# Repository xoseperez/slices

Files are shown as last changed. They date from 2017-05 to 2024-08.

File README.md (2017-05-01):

# Slices

Slices is an ESP8266 based clock with a LED matrix display.

It's an evolution of a previous project ([a wordclock](http://tinkerman.cat/wordlock)), with the following goals:

* Replace the ATMega328P with an ESP8266 (NTP support and user interaction)
* Smaller sizes (8x8 LED matrices)
* Smaller PCB, less buttons (version 3.0 of the [DaClock](http://github.com/xoseperez/daclock) board)
* Add buzzer for alarms
* Replace the 3D printed part with a MDF grid cut in laser
* Completely closed enclosure, better presentation
* Fix some issues with the original board (like the lack of a beefy capacitor across the LED matrix power lines).

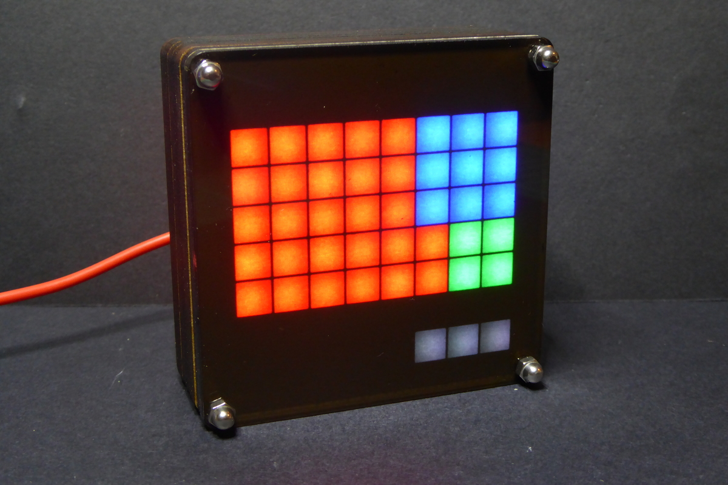
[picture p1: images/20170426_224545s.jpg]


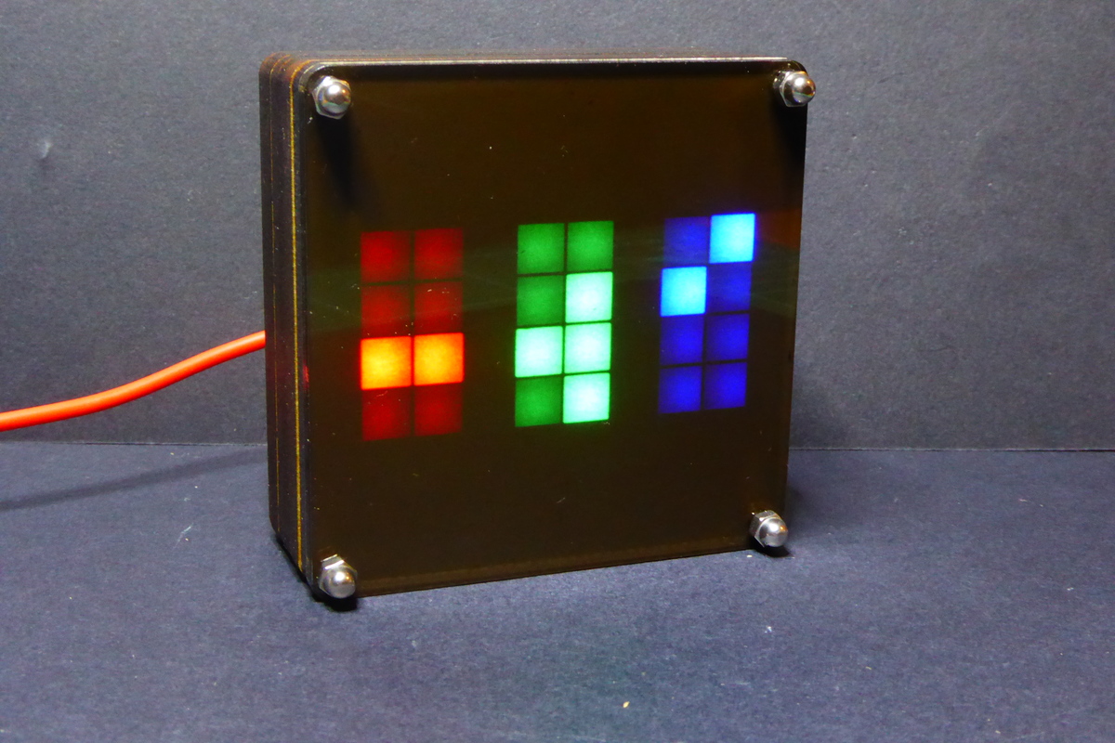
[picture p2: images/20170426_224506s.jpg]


## Hardware

### The clock

The hardware has been designed using [OpenSCad](http://www.openscad.org)
and it's inspired by the [PiBow](https://www.raspberrypi.org/blog/pibow/)
cases for Raspberry Pi. A series of layers forming a sandwich. From top to bottom
the layers are (this is true for beta version):

* front, a smoke colored acrylic layer cut with a laser cutter
* stencil (optional), a thin black cardboard with the characters cut out with a laser
* diffusor, a thin white paper sheet
* grid, a 3D printed black PLA grid to isolate each pixel or a thick laser cut MDF
* LED matrix, a 16x16 flexible RGB LED Matrix or a 8x8 PCB based one w/ WS2812B pixels
* LED matrix support in MDF
* MDF hollow layers to allow room for the electronics
* controller, custom PCB attached to the backend
* back, a clear acrylic layer or MDF again with holes for the power connector and button

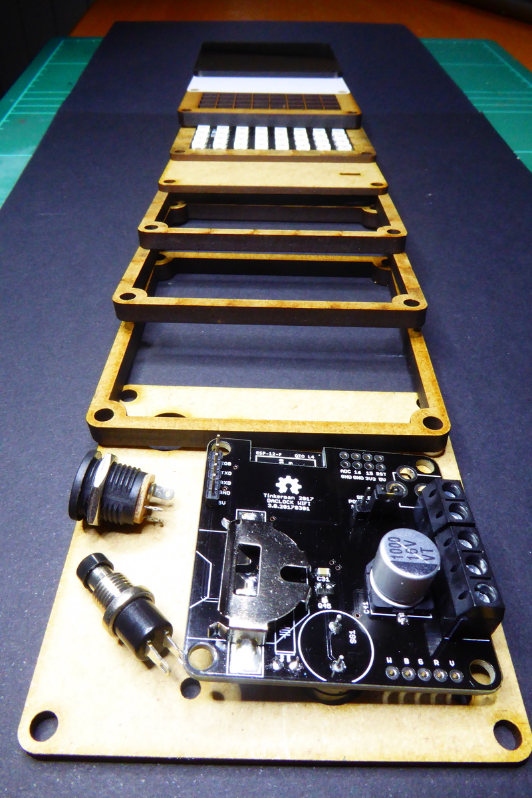
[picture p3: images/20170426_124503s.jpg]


### The controller

The controller is based on the the [DaClock](http://github.com/xoseperez/daclock)
board and it's designed to serve different purposes. This project uses version 3.0
of that board.

It features a ESP8266 ESP12E/F module, a DS1337 RTC clock, a buzzer for notifications
and connectors to drive a WS2812 LED matrix.

## Firmware

The project is ready to be build using [PlatformIO](http://www.platformio.org).
Please refer to their web page for instructions on how to install the builder.
Once installed:

```bash
> cd code
> platformio run
> platformio run --target upload
```

Library dependencies are automatically managed via PlatformIO Library Manager.

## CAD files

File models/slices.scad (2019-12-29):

//-----------------------------------
// CONFIGURATION
//-----------------------------------

// Matrix 16x16
grid_size=16;
grid_step=10;
grid_shift=0;

// Matrix 8x8
//grid_size=8;
//grid_step=8;
//grid_shift=0.4;

// Matrix 10x10
//grid_size=8;
//grid_step=10;
//grid_shift=0;

// LED circle 60
led_radius_inner=72.39;
led_radius_outer=78.74;
led_radius=(led_radius_inner+led_radius_outer)/2;
led_width=(led_radius_outer-led_radius_inner);
led_side=6;
led_count=60;
led_angle_shift=0;
led_circle_grid=1;

// LED circle 24
//led_radius_inner=72.22/2;
//led_radius_outer=85.5/2;
//led_radius=(led_radius_inner+led_radius_outer)/2;
//led_width=(led_radius_outer-led_radius_inner);
//led_side=6;
//led_count=24;
//led_angle_shift=0;
//led_circle_grid=0;

// General settings
grid_wall=1;
grid_height=5;
hole_size=4;
chamfer_size=4;
//font = "Ubuntu:style=Bold";
font = "AG Stencil:style=AG Stencil";

// Text for the 4 buttons in version 1
button_text = [
    "MODE",
    "LANGUAGE",
    "COLOR",
    "BRIGHTNESS"
];

// Stencil of characters for 16x16 matrix (catalan & spanish)
list_esp_cat_16 = [
    "ésónesonvoracasi",
    //"undostreslangmig",
    "unodostreslngmig", //<- add "uno"
    "quarts1imenysmig",
    "cinc2ben34tocats",
    "lesdelasduesiset",
    "cincochovuit&una",
    "dosnuevediezonce",
    "quatreseiscuatro",
    "sietedoce5ymenos",
    "&onzedotzenoudeu",
    "veinticincomedia",
    "cuartodiezveinte",
    "ben6tocadespunto",
    "tocadapasadas789",
    "dellamatinitarda",
    "mañanatardenoche"
];

// Stencil of characters for the 8x8 matrix (catalan)
list_cat_8 = [
    "1dos3les",
    "laquarts",
    "de0dotze",
    "&unacinc",
    "duesiset",
    "quatres0",
    "vuitnou0",
    "deu&onze"
];

//-----------------------------------

// Front face (translucid or dark acrylic, also for the difuser)
//layer_front(); 

// Character stencial (pass stencil array as argument)
layer_stencil(list_esp_cat_16);

// Grid (choose either a 3D model or a 2D model to laser cut)
//layer_grid_3D();
//layer_grid_2D();
//linear_extrude(4)
//layer_grid_circle();

// Layer to hold the PCB matrix layer in place (only for v2)
//layer_matrix();
//translate([0,0,2.5])
//linear_extrude(2.5)
//layer_matrix_circle();

// Matrix support layer, with cutouts for the cables, choose either version 1 or 2
//layer_support_v1();
//layer_support_v2();
//translate([0,0,2.5])
//linear_extrude(2.5)
//layer_support_circle();

// Hollow layer
//layer_hollow();

// Back layer
//layer_back_v1();
//layer_back_v2();

// demo
//linear_extrude(4)
//    sonometre();
//translate([0,0,-12])
//    linear_extrude(12)
//        layer_hollow();
//translate([0,0,-16])
//    linear_extrude(4)
//        layer_back_v2();

//-----------------------------------

module sonometre() {
    difference() {
        layer_grid_circle();
        translate([50,60])
            circle(5, $fn=50);    
        translate([50,40])
            circle(5, $fn=50);    
    }
}

module base(size, step, chamfer, hole) {
    size = (size+2)*step;
    difference() {
        translate([chamfer, chamfer, 0]) {
            minkowski() {
                square(size-2*chamfer);
                circle(chamfer, $fn=50);
            }
        }
        hole = hole / 2;
        hole_center = (step) / 2;
        translate([hole_center,hole_center,0]) {
            circle(hole, center=true, $fn=50);
        }
        translate([size-hole_center,hole_center,0]) {
            circle(hole, center=true, $fn=50);
        }
        translate([size-hole_center,size-hole_center,0]) {
            circle(hole, center=true, $fn=50);
        }
        translate([hole_center,size-hole_center,0]) {
            circle(hole, center=true, $fn=50);
        }
    }
}

module grid(size, step, wall) {
    for (x=[1:size]) {
        for (y=[1:size]) {
            translate([x*step+wall/2,y*step+wall/2,0]) {
                square(step-wall);
            }
        }
    }
}

module subgrid(size, step, wall) {
    for (x=[1:size]) {
        translate([x*step+wall/2,wall/2,wall]) {
            cube([step-wall,step-wall,step]);
        }
        translate([x*step+wall/2,(size+1)*step+wall/2,wall]) {
            cube([step-wall,step-wall,step]);
        }
    }
    for (y=[1:size]) {
        translate([wall/2,y*step+wall/2,wall]) {
            cube([step-wall,step-wall,step]);
        }
        translate([(size+1)*step+wall/2,y*step+wall/2,wall]) {
            cube([step-wall,step-wall,step]);
        }
    }
}

module layer_grid_circle() {

    difference() {
        base(grid_size, grid_step, chamfer_size, hole_size);
        offset = (grid_size+2)*grid_step/2;
        translate([offset,offset]) {
            for (i=[0:led_count]) {
                rotate(360 * (i+led_angle_shift)/led_count)
                    translate([0, led_radius])
                        square([led_side, led_side], true);
            }
        }
        if (led_circle_grid)        
            translate([50,50])
                grid(8, 8, 1);
    }
}
    
module layer_matrix_circle() {

    difference() {
        base(grid_size, grid_step, chamfer_size, hole_size);
        offset = (grid_size+2)*grid_step/2;
        translate([offset,offset]) {
            difference() {
                circle(led_radius_outer, $fn=100);
                circle(led_radius_inner, $fn=100);
            }
        }
        if (led_circle_grid)
            translate([58,58])
                square([64,64]);
    }
}

module layer_grid_2D()  {
        difference() {
            base(grid_size, grid_step, chamfer_size, hole_size);
            translate([0, grid_shift])
                grid(grid_size, grid_step, grid_wall);
        }
}

module layer_grid_3D() {
    difference() {
        linear_extrude(grid_height) layer_grid_2D();
        subgrid(grid_size, grid_step, grid_wall);
    }
}

module arc(max, min) {
    union() {
        intersection() {
            difference() {
                circle(max, $fn=50);
                circle(min, $fn=50);
            }
            square(max,center=false);
        }
        translate([0,min]) square([5, 15-min], center=false);
    }
}

module layer_front() {
    base(grid_size, grid_step, chamfer_size, hole_size);
}

module layer_support_v1() {
    difference() {
        base(grid_size, grid_step, chamfer_size, hole_size);
        translate([5,5,0]) arc(10,5);
        translate([(grid_size+2)*grid_step-5,5,0]) {
            mirror([1,0,0]) arc(10,5);
        }
    }
}

module layer_support_v2() {
    difference() {
        base(grid_size, grid_step, chamfer_size, hole_size);
        translate([grid_step*1.5,grid_step*8 + 1,0]) {
            square([1.5*(grid_step-grid_wall),grid_wall*4], true);
        }
        translate([grid_step*8.5,grid_step*2 - 1,0]) {
            square([1.5*(grid_step-grid_wall),grid_wall*4], true);
        }
    }
}

module layer_support_circle() {
    difference() {
        base(grid_size, grid_step, chamfer_size, hole_size);
        offset = (grid_size+2)*grid_step/2;
        shift = 360*(0.5-led_angle_shift)/led_count;
        translate([offset,offset]) {
            for (i=[0:3]) {
                rotate(90*i-shift)
                    translate([0, led_radius])
                        square([led_width*2,led_width], true);
            }
        }
        if (led_circle_grid)
            translate([64, 64]) {
                translate([8*0,8*6]) {
                    square([1.75*(8-1),1*4], false);
                }
                translate([8*5,8*0,0]) {
                    square([1.75*(8-1),1*4], false);
                }
            }
    }
}

module layer_hollow() {
    border = grid_step/2;
    size = (grid_size+2)*grid_step - border*2;
    difference() {
        base(grid_size, grid_step, chamfer_size, hole_size);
        translate([border,border]) 
            difference() {
                square(size);
                circle(5, $fn=50);
                translate([size,0]) circle(5, $fn=50);
                translate([size,size]) circle(5, $fn=50);
                translate([0,size]) circle(5, $fn=50);
            }
    }
}

module wall_hole() {
    minkowski() {
        square([0.1,15], center=true);
        circle(3, $fn=50);
    }
}

module socket_hole() {
    circle(11.4/2, $fn=50);
}

module buttons() {
    for (x=[0:3]) {
        translate([0,x*12]) {
            circle(3.6, $fn=50);
            translate([6,-2.5]) 
                text(button_text[x], 6, font,"right","center");
        }
    }
}

module layer_back_v1() {
    difference() {
        base(grid_size, grid_step, chamfer_size, hole_size);
        translate([50,30,0]) wall_hole();
        translate([(grid_size+2)*grid_step-50,30,0]) wall_hole();
        translate([(180-51)/2-4,110+(180-80)/2+4,0])
            rotate(-90)
                pcbfootprint();
    }
}
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

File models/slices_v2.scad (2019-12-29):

//-----------------------------------
// Layers to render
//-----------------------------------

//layer_front(); 
//layer_grid();
//layer_cast();
//layer_support();
//layer_hollow();
//layer_hollow_broken_middle();
//layer_hollow_broken_side();
//layer_back_wall();
//layer_back_v2();
//layer_back_v3(0);

//-----------------------------------
// Components to display
//-----------------------------------

show_big_square_grid=0;
show_small_square_grid=0;
show_two_small_square_grid=0;
show_big_circle_grid=0;
show_small_circle_grid=1;
show_potentiometer=1;
show_microphone=1;
show_fibonacci=0;

//-----------------------------------
// Configuration
//-----------------------------------

// Model size
//model_size=180;
model_size=100;
//model_size=80;

// Grid types (size, step, shift, wall)
grid = [
    [16, 10, 0, 1],
    [8, 8, 0.4, 1]
];

// Circle types (count, inner, outer)
circle = [
    [60, 71.5, 79.5],
    [24, 35.5, 43.5]
];

// Height of the grid (widt of the wood)
wood_width=4;

// Size of an individual LED
led_side=6;

// Shift LED circle 
led_shift = 0;

// Holes radius (half of metric: M3, M4...)
hole_size=2; // M4

// Hole distance to edge
hole_distance=5;

// Minkowski radius
chamfer_size=4;

// Fonts
//font = "Ubuntu:style=Bold";
font = "AG Stencil:style=AG Stencil";

//-----------------------------------
// DO NOT TOUCH BELOW THIS LINE
//-----------------------------------

//-----------------------------------
// Components
//-----------------------------------

module base() {
    
    difference() {
        
        // Shape
        minkowski() {
            square(model_size-2*chamfer_size, true);
            circle(chamfer_size, $fn=50);
        }

        // Holes
        for(i=[0:3]) {
            rotate(90*i) {
                translate([model_size/2-hole_distance,model_size/2-hole_distance,0]) {
                    circle(hole_size, center=true, $fn=50);
                }
            }
        }

    }
}

module fibonacci_block(type, number, x, y) {
    
    size = grid[type][0];
    step = grid[type][1] * (type == 0 ? 2 : 1);
    shift = grid[type][2];
    wall = grid[type][3];

    width = step * number - wall;
    x = x * step + wall/2;
    y = y * step + wall/2;
    translate([x,y]) square(width);

}

module fibonacci_negative(type) {

    size = grid[type][0];
    step = grid[type][1];
    shift = grid[type][2];
    wall = grid[type][3];
    
    translate([shift-size*step/2,-size*step/2]) {
        
        union() {
            fibonacci_block(type, 5, 0, 2);
            fibonacci_block(type, 3, 5, 4);
            fibonacci_block(type, 2, 6, 2);
            fibonacci_block(type, 1, 5, 3);
            fibonacci_block(type, 1, 5, 2);
        }

    }
    
}

module led_matrix_negative(type) {

    size = grid[type][0];
    step = grid[type][1];
    shift = grid[type][2];
    wall = grid[type][3];
    
    translate([shift-size*step/2,-size*step/2])
    for (x=[0:size-1]) {
        for (y=[0:size-1]) {
            translate([x*step+wall/2,y*step+wall/2,0]) {
                square(step-wall);
            }
        }
    }

}

module led_circle_negative(type, led_side, shift) {

    count = circle[type][0];
    inner = circle[type][1];
    outer = circle[type][2];
    radius = (inner + outer)/2;

    for (i=[0:count]) {
        rotate(360 * (i+shift) / count)
            translate([0, radius])
                square([led_side, led_side], true);
    }

}
    
module arc(max, min) {
    union() {
        intersection() {
            difference() {
                circle(max, $fn=50);
                circle(min, $fn=50);
            }
            square(max,center=false);
        }
        translate([0,min]) square([5, 15-min], center=false);
    }
}

module joint() {
    size = hole_size/0.75;
    translate([-size/2-0.25,0])
        union() {
            circle(size/2, $fn=50);
            translate([0,-size/4])
                square([size, size/2]);
        }
}

module potentiometer_negative(mark=0, body=0) {
    if (body==0) circle(4, $fn=50);
    if (mark) {
        translate([7.5,0,0])
            square([1,2.5], true);
        translate([-7.5,0,0])
            square([1,2.5], true);
    }
    if (body==1) circle(16, $fn=50);
}

module mic_negative(body=0) {
    union() {
        circle(5, $fn=50);
        if (body==1) square([12,3], true);
    }
}

module wall_hole() {
    rotate(180)
        minkowski() {
            square([0.1,15]);
            circle(3, $fn=50);
        }
}

module socket_hole() {
    circle(11.4/2, $fn=50);
}

module pcbfootprint_daclock_v2(hole=4) {

    // HOLES
    hole = hole / 2;
    translate([4,4,0]) {
        circle(hole, center=true, $fn=50);
    }
    translate([84,4,0]) {
        circle(hole, center=true, $fn=50);
    }
    translate([4,55,0]) {
        circle(hole, center=true, $fn=50);
    }
    translate([84,55,0]) {
        circle(hole, center=true, $fn=50);
    }
    
    // BUTTONS
    //translate([23,44,0]) {
        //square([54,13]);
    //}
    
    // SPEAKER
    translate([49, 36]) circle(6.5, $fn=50);

}


module pcbfootprint_daclock_v3() {
    
    hole_vector = sqrt(22*22*2);
    
    // PCB holes
    for(i = [45:90:315]) {
        rotate([0,0,i]) {
            translate([0,hole_vector]) {
                circle(1.5, $fn=50);
            }
        }
    }
    
    // speaker
    translate([1,3.5-22]) {
        circle(6.5, $fn=50);
    }
    

}

//-----------------------------------
// Layers
//-----------------------------------

module layer_front() {
    difference() {
        base();
        if (show_potentiometer) translate([0, -15]) potentiometer_negative(0);
        if (show_microphone) translate([0, 15]) mic_negative(0);
    }
}

module layer_grid() {

    difference() {
        
        base();
        
        if (show_big_square_grid) {
            led_matrix_negative(0);
            if (show_fibonacci) fibonacci_negative(0);
        }
        if (show_small_square_grid) {
            led_matrix_negative(1);
            if (show_fibonacci) fibonacci_negative(1);
        }
        if (show_two_small_square_grid) {
            translate([grid[1][0]*grid[1][1]/2-grid[1][2],0]) 
                led_matrix_negative(1);
            translate([-grid[1][0]*grid[1][1]/2-grid[1][2],0]) 
                led_matrix_negative(1);
        }
        if (show_big_circle_grid) 
            led_circle_negative(0, led_side, led_shift);
        if (show_small_circle_grid) 
            led_circle_negative(1, led_side, led_shift);
        
        if (show_potentiometer) translate([0,-15]) potentiometer_negative(1,0);
        if (show_microphone) translate([0,15]) mic_negative(0);
        
    }


}

module layer_cast() {

    difference() {
        
        base();
        
        if (show_big_square_grid) 
            square(grid[0][0]*grid[0][1]+2, true);
        if (show_small_square_grid)
            square(grid[1][0]*grid[1][1]+2, true);
        if (show_two_small_square_grid)
            square([grid[1][0]*grid[1][1]*2+2,grid[1][0]*grid[1][1]+2], true);
        if (show_big_circle_grid) {
            difference() {
                circle(circle[0][2], center=true, $fn=100);
                circle(circle[0][1], center=true, $fn=100);
            }
        }
        if (show_small_circle_grid) {
            difference() {
                circle(circle[1][2], center=true, $fn=100);
                circle(circle[1][1], center=true, $fn=100);
            }
        }
        if (show_potentiometer) translate([0,-15]) potentiometer_negative(1,0);
        if (show_microphone) translate([0,15]) mic_negative(1);
        
    }

}

module layer_support() {

    difference() {
        
        base();
        
        if (show_big_square_grid) {

            translate([
                model_size/2-hole_distance,
                model_size/2-hole_distance
            ]) rotate(180) arc(10,5);
            translate([
                -model_size/2+hole_distance,
                model_size/2-hole_distance
            ]) rotate(180) mirror([1,0,0]) arc(10,5);
        }
        
        if (show_small_square_grid || show_two_small_square_grid) {

            size = grid[1][0];
            step = grid[1][1];
            shift = grid[1][2];
            wall = grid[1][3];
            
            height = size;
            width = show_two_small_square_grid ? height * 2 : height;

            translate([0, step*(height/2-1)])
                square([step*width,step*2], true);
            translate([0, -step*(height/2-1)])
                square([step*width,step*2], true);


            
        }
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

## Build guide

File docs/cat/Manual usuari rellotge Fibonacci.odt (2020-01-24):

1:24 | 3:30
5:49 | 7:17
9:26 | 9:26 (també)
Mitjanit (0:00) | Migdia (12:00)

Rellotge de Fibonacci

La sèrie de Fibonacci és aquella on cada número és la suma dels dos anteriors de la sèrie: 1, 1, 2, 3, 5, 8, 13, ... El Rellotge de Fibonacci està compost per diferents àrees que tenen de costat els primers 5 números de la sèrie, que sumen 12 (1+1+2+3+5).

Com es calcula l’hora?

- Sumant els valors de les àrees en vermell i blau tens les hores.
- Sumant els valors de les àrees en verd i blau, multiplicant per 5 i sumant els els quadradets en taronja (M) tens els minuts.

Una mateixa hora es pot representar amb combinacions diferents. Les 5, per exemple, poden ser 1+1+3 o 2+3 o només 5. El mateix passa amb els minuts, de manera que el rellotge acostuma a mostrar l’hora d’una manera molt acolorida i diferent cada vegada.

A més, prement el botó del darrera, pots canviar entre mode rellotge o mode làmpada de colors.

El Rellotge de Fibonacci està pensat perquè es posi en hora automàticament a través d’Internet. Per fer-ho caldrà que el tinguis connectat al teu router de casa. Si prefereixes no fer-ho també hi ha la opció de posar-lo en hora manualment. Si aquest és el cas salta a l’apartat «Configuració manual».

Connectar-lo a la WiFi via WPS

La manera més ràpida de connectar el rellotge a la WiFi de casa és via el protocol WPS que incorporen la majoria de routers domèstics. Normalment hi ha un botó físic en el router etiquetat «WPS» que cal prémer durant uns segons (o fer doble-clic) per activar aquesta opció. Consulta el manual del teu router per saber si té WPS i com activar-lo.

Per configurar la connexió fent servir WPS cal seguir aquestes passes (millor si estàs a prop del router):

1. Desendolla el rellotge
2. Activa el mode WPS del teu router
3. Prem i no deixis anar el botó de la part del darrera del rellotge
4. Endolla el rellotge
5. Quan l’indicador d’estat estigui porpra ja pots deixar anar el botó

Si la negociació amb el router té èxit l’indicador d’estat canviarà a taronja (connectant) i després a verd (connectat). En aquest moment el rellotge consultarà l’hora i aquesta s’actualitzarà. Si l’indicador d’estat passa a vermell o està en porpra més d’un minut prova repetir el procediment. En cas de que continuï sense funcionar passa al procés de configuració manual (següent apartat).

Configuració manual

Amb el rellotge endollat i l’indicador d’estat apagat, fes doble clic al botó. L’indicador d’estat passarà a blau indicant que el rellotge ha creat un xarxa WiFi que pots fer servir per connectar-te i configurar-lo.

Pots buscar aquesta xarxa WiFi amb el teu mòbil o ordinador. El seu nom serà «SLICES_XXXXXX» on les X són números i lletres. Per defecte és una xarxa oberta, sense mot de pas. Un cop connectat obre un navegador web i vés a l’adreça «http://192.168.4.1».

Se’t presentarà un lloc web de configuració amb diferents opcions. A continuació tens una petita explicació de les més importants.

Des de la pestanya STATUS pots sincronitzar l’hora del rellotge amb la del teu ordinador o mòbil prement el botó «Sync».

Des de la pestanya WIFI pots configurar manualment la connexió al router de casa teva prement «Add Network». Es poden configurar diferents connexions.

Des de la pestanya TIME pots definir com vols sincronitzar el rellotge. Les opcions són:

- Connectar-se cada X hores: si el rellotge disposa de les credencials de connexió al nostre router, aquest es connectarà a la WiFi cada X hores i sincronitzarà l’hora per Internet. Pots indicar un valor d’hores d’entre 1 (cada hora, no recomanable) i 168 (un cop a la setmana).
- Connectar-se cada dia a una hora concreta: si el rellotge disposa de les credencials de connexió al nostre router, aquest es connectarà a la WiFi a l’hora indicada i sincronitzarà l’hora per Internet. Això és útil si només tens la WiFi accessible a determinades hores del dia.
- No connectar-se, només manualment: en aquest cas el rellotge no es connectarà automàticament i hauràs de fer doble clic al botó del rellotge perquè aquest es connecti a Internet per consultar l’hora o, si no té les dades de la WiFi, generar un punt d’accés propi per connectar-se i sincronitzar l’hora manualment tal com s’ha explicat en aquest mateix apartat.

Alimentació

El rellotge s’ha d’alimentar a 5V i un mínim de 0.5A. El connector és de tipus 5.5x2.1mm, centre positiu.

Indicador d’estat

Un dels «píxels» del rellotge és l’indicador d’estat («E» a la figura de la primera plana). El color d’aquest indica l’estat en el que es troba la connexió.

Aquest és un producte de codi i maquinari lliures dissenyat i fabricat per Xose Pérez (xose@tinkerman.cat). En els següents enllaços pots trobar les fonts de codi, disseny de la caixa i de l’electrònica així com documentació sobre l’ús del rellotge.

https://github.com/xoseperez/slices
https://github.com/xoseperez/daclock

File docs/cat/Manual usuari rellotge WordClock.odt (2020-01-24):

WordClock

Un wordclock o rellotge de paraules és un tipus de rellotge que «diu» l’hora en comptes de «marcar» l’hora. Per saber quina hora és simplement s’ha de llegir: «són vora tres quarts de sis de la tarda».

e | s | ó | n | e | s | o | n | v | o | r | a | c | a | s | i
u | n | o | d | o | s | t | r | e | s | l | n | g | m | i | g
q | u | a | r | t | s | 1 | i | m | e | n | y | s | m | i | g
c | i | n | c | 2 | b | e | n | 3 | 4 | t | o | c | a | t | s
l | e | s | d | e | l | a | s | d | u | e | s | i | s | e | t
c | i | n | c | o | c | h | o | v | u | i | t | d’ | u | n | a
d | o | s | n | u | e | v | e | d | i | e | z | o | n | c | e
q | u | a | t | r | e | s | e | i | s | c | u | a | t | r | o
s | i | e | t | e | d | o | c | e | 5 | y | m | e | n | o | s
d’ | o | n | z | e | d | o | t | z | e | n | o | u | d | e | u
v | e | i | n | t | i | c | i | n | c | o | m | e | d | i | a
c | u | a | t | r | o | d | i | e | z | v | e | i | n | t | e
b | e | n | 6 | t | o | c | a | d | e | s | p | u | n | t | o
t | o | c | a | d | a | p | a | s | a | d | a | s | 7 | 8 | 9
d | e | l | l | a | m | a | T | í | n | i | t | a | r | d | a
m | a | ñ | a | n | a | t | a | r | d | e | n | o | c | h | e

Evidentment l’hora dita dependrà de l’idioma. Aquest rellotge diu la hora en català o castellà, en funció del mode en el que es trobi. Per canviar de mode només cal prémer un cop el botó del darrera del rellotge. Els modes disponibles són:

Hora en català Hora en castellà | Hora en català amb «efecte matrix» Hora en castellà amb «efecte matrix»

El WordClock està pensat perquè es posi en hora automàticament a través d’Internet. Per fer-ho caldrà que el tinguis connectat al teu router de casa. Si prefereixes no fer-ho també hi ha la opció de posar-lo en hora manualment. Si aquest és el cas salta a l’apartat «Configuració manual».

Connectar-lo a la WiFi via WPS

La manera més ràpida de connectar el rellotge a la WiFi de casa és via el protocol WPS que incorporen la majoria de routers domèstics. Normalment hi ha un botó físic en el router etiquetat «WPS» que cal prémer durant uns segons (o fer doble-clic) per activar aquesta opció. Consulta el manual del teu router per saber si té WPS i com activar-lo.

Per configurar la connexió fent servir WPS cal seguir aquestes passes (millor si estàs a prop del router):

1. Desendolla el rellotge
2. Activa el mode WPS del teu router
3. Prem i no deixis anar el botó de la part del darrera del rellotge
4. Endolla el rellotge
5. Quan vegis un «1» blau fosc a la pantalla ja pots deixar anar el botó

Si la negociació amb el router té èxit s’il·luminarà un «3» (connectant) i després un «4» (connectat). En aquest moment el rellotge consultarà l’hora i aquesta s’actualitzarà. Si en comptes d’això el rellotge mostra un «5» blau o aquest «1» està estàtic més d’un minut prova repetir el procediment. En cas de que continuï sense funcionar passa al procés de configuració manual (següent apartat).

Configuració manual

Amb el rellotge endollat i cap número a la pantalla, fes doble clic al botó. Es mostrarà breument un «2» blau a la pantalla indicant que el rellotge ha creat un xarxa WiFi que pots fer servir per connectar-te i configurar-lo.

Pots buscar aquesta xarxa WiFi amb el teu mòbil o ordinador. El seu nom serà «SLICES_XXXXXX» on les X són números i lletres. Per defecte és una xarxa oberta, sense mot de pas. Un cop connectat obre un navegador web i vés a l’adreça «http://192.168.4.1».

Se’t presentarà un lloc web de configuració amb diferents opcions. A continuació tens una petita explicació de les més importants.

Des de la pestanya STATUS pots sincronitzar l’hora del rellotge amb la del teu ordinador o mòbil prement el botó «Sync».

Des de la pestanya WIFI pots configurar manualment la connexió al router de casa teva prement «Add Network». Es poden configurar diferents connexions.

Des de la pestanya TIME pots definir com vols sincronitzar el rellotge. Les opcions són:

- Connectar-se cada X hores: si el rellotge disposa de les credencials de connexió al nostre router, aquest es connectarà a la WiFi cada X hores i sincronitzarà l’hora per Internet. Pots indicar un valor d’hores d’entre 1 (cada hora, no recomanable) i 168 (un cop a la setmana).
- Connectar-se cada dia a una hora concreta: si el rellotge disposa de les credencials de connexió al nostre router, aquest es connectarà a la WiFi a l’hora indicada i sincronitzarà l’hora per Internet. Això és útil si només tens la WiFi accessible a determinades hores del dia.
- No connectar-se, només manualment: en aquest cas el rellotge no es connectarà automàticament i hauràs de fer doble clic al botó del rellotge perquè aquest es connecti a Internet per consultar l’hora o, si no té les dades de la WiFi, generar un punt d’accés propi per connectar-se i sincronitzar l’hora manualment tal com s’ha explicat en aquest mateix apartat.

Alimentació

El rellotge s’ha d’alimentar a 5V i un mínim de 1A. El connector és de tipus 5.5x2.1mm, centre positiu.

Indicador d’estat

En determinats moments el rellotge mostra un número de color blau fosc en pantalla. Aquest número és informatiu de l’estat en el que es troba la connexió WiFi. Els possibles valors són:

WPS Connectant-se al router Connectat al router | Punt d’accés Error

Aquest és un producte de codi i maquinari lliures dissenyat i fabricat per Xose Pérez (xose@tinkerman.cat). En els següents enllaços pots trobar les fonts de codi, disseny de la caixa i de l’electrònica així com documentació sobre l’ús del rellotge.

https://github.com/xoseperez/slices
https://github.com/xoseperez/daclock

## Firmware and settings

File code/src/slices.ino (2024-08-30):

/*

slices

Copyright (C) 2017-2024 by Xose Pérez <xose dot perez at gmail dot com>

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
*/

#include "config/all.h"
#include <Wire.h>

// -----------------------------------------------------------------------------
// METHODS
// -----------------------------------------------------------------------------

void heartbeat() {

    static unsigned long last_uptime = 0;
    static unsigned char uptime_overflows = 0;

    if (millis() < last_uptime) ++uptime_overflows;
    last_uptime = millis();
    unsigned long uptime_seconds = uptime_overflows * (UPTIME_OVERFLOW / 1000) + (last_uptime / 1000);
    unsigned int free_heap = ESP.getFreeHeap();

    DEBUG_MSG_P(PSTR("[MAIN] Uptime: %ld seconds\n"), uptime_seconds);
    DEBUG_MSG_P(PSTR("[MAIN] Free heap: %d bytes\n"), free_heap);
    #if ENABLE_ADC_VCC
        DEBUG_MSG_P(PSTR("[MAIN] Power: %d mV\n"), ESP.getVcc());
    #endif

    #if ENABLE_MQTT

        #if (MQTT_REPORT_INTERVAL)
            mqttSend(MQTT_TOPIC_INTERVAL, HEARTBEAT_INTERVAL / 1000);
        #endif
        #if (MQTT_REPORT_APP)
            mqttSend(MQTT_TOPIC_APP, APP_NAME);
        #endif
        #if (MQTT_REPORT_VERSION)
            mqttSend(MQTT_TOPIC_VERSION, APP_VERSION);
        #endif
        #if (MQTT_REPORT_HOSTNAME)
            mqttSend(MQTT_TOPIC_HOSTNAME, getSetting("hostname").c_str());
        #endif
        #if (MQTT_REPORT_IP)
            mqttSend(MQTT_TOPIC_IP, getIP().c_str());
        #endif
        #if (MQTT_REPORT_MAC)
            mqttSend(MQTT_TOPIC_MAC, WiFi.macAddress().c_str());
        #endif
        #if (MQTT_REPORT_RSSI)
            mqttSend(MQTT_TOPIC_RSSI, String(WiFi.RSSI()).c_str());
        #endif
        #if (MQTT_REPORT_UPTIME)
            mqttSend(MQTT_TOPIC_UPTIME, String(uptime_seconds).c_str());
        #endif
        #if (MQTT_REPORT_FREEHEAP)
            mqttSend(MQTT_TOPIC_FREEHEAP, String(free_heap).c_str());
        #endif
        #if (MQTT_REPORT_STATUS)
            mqttSend(MQTT_TOPIC_STATUS, MQTT_STATUS_ONLINE);
        #endif

    #endif

}

void hardwareSetup() {
    Serial.begin(SERIAL_BAUDRATE);
    Wire.begin(SDA_PIN, SCL_PIN);
}

void hardwareLoop() {

    // Heartbeat
    static unsigned long last_uptime = 0;
    if ((millis() - last_uptime > HEARTBEAT_INTERVAL) || (last_uptime == 0)) {
        last_uptime = millis();
        heartbeat();
    }

}

// -----------------------------------------------------------------------------
// BOOTING
// -----------------------------------------------------------------------------

void welcome() {

    DEBUG_MSG_P(PSTR("%s %s\n"), (char *) APP_NAME, (char *) APP_VERSION);
    DEBUG_MSG_P(PSTR("%s\n%s\n\n"), (char *) APP_AUTHOR, (char *) APP_WEBSITE);
    DEBUG_MSG_P(PSTR("ChipID: %06X\n"), ESP.getChipId());
    DEBUG_MSG_P(PSTR("CPU frequency: %d MHz\n"), ESP.getCpuFreqMHz());
    DEBUG_MSG_P(PSTR("Last reset reason: %s\n"), (char *) ESP.getResetReason().c_str());
    DEBUG_MSG_P(PSTR("Memory size (SDK): %d bytes\n"), ESP.getFlashChipSize());
    DEBUG_MSG_P(PSTR("Memory size (CHIP): %d bytes\n"), ESP.getFlashChipRealSize());
    DEBUG_MSG_P(PSTR("Free heap: %d bytes\n"), ESP.getFreeHeap());
    DEBUG_MSG_P(PSTR("Firmware size: %d bytes\n"), ESP.getSketchSize());
    DEBUG_MSG_P(PSTR("Free firmware space: %d bytes\n"), ESP.getFreeSketchSpace());
    DEBUG_MSG_P(PSTR("\n\n"));

}

void setup() {

    hardwareSetup();
    welcome();

    eepromSetup();
    settingsSetup();
    if (getSetting("hostname").length() == 0) {
        setSetting("hostname", getIdentifier());
        saveSettings();
    }

    i2c_scanner();

    rtcSetup();
    webSetup();
    buttonSetup();
    soundSetup();

    delay(500);

    wifiSetup();
    otaSetup();
    terminalSetup();
    #if ENABLE_MDNS
    mdnsServerSetup();
    #endif
    #if ENABLE_MQTT
    mqttSetup();
    #endif
    ntpSetup();

    matrixSetup();

    // drivers
    #if ENABLE_DRIVER_BASIC
        basicClockSetup();
    #endif
    #if ENABLE_DRIVER_SCROLL
        scrollClockSetup();
    #endif
    #if ENABLE_DRIVER_WORDCLOCK
        wordClockSetup();
    #endif
    #if ENABLE_DRIVER_FIBONACCI
        fibonacciClockSetup();
    #endif
    #if ENABLE_DRIVER_FIBONACCI_MOOD
        fibonacciMoodSetup();
    #endif
    #if ENABLE_DRIVER_BINARY
        binaryClockSetup();
    #endif
    #if ENABLE_DRIVER_GAME_OF_LIFE
        gameOfLifeSetup();
    #endif
    #if ENABLE_DRIVER_CANVAS
        canvasSetup();
    #endif
    #if ENABLE_DRIVER_CIRCLE
        circleClockSetup();
    #endif
    #if ENABLE_DRIVER_GAUGE
        gaugeClockSetup();
    #endif

    driverSetup();

}

void loop() {

    eepromLoop();
    hardwareLoop();
    buttonLoop();
    wifiLoop();
    otaLoop();
    #if ENABLE_MQTT
    mqttLoop();
    #endif
    ntpLoop();
    terminalLoop();
    
    driverLoop();

}

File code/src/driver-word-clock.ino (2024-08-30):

/*

WORD CLOCK DRIVER

Copyright (C) 2017-2024 by Xose Pérez <xose dot perez at gmail dot com>

*/

#if ENABLE_DRIVER_WORDCLOCK

#include <FastLED_GFX.h>
#include "driver-word-clock.h"

int _word_previous_hour = -1;
int _word_previous_minute = -1;
bool _word_force = false;
unsigned int _wordclock_time_pattern[16] = {0};

// -----------------------------------------------------------------------------
// DRIVER
// -----------------------------------------------------------------------------

/**
 * Loads a word code into the time pattern
 * @param  clockword code          a tupla defining the leds to be lit to form a word
 * @param  unsigned  int *         LED pattern array representation
 */
void _wordClockLoadCode(clockword code, unsigned int * pattern) {
   pattern[code.row] = pattern[code.row] | code.positions;
}

void _wordClockSpanish(byte hour, byte minute, unsigned int * pattern) {

    /*

    00 => en punto
    01 => pasada/s
    02 => pasada/s

    03 => casi y cinco
    04 => casi y cinco
    05 => y cinco
    06 => y cinco pasadas
    07 => y cinco pasadas

    08 => casi y diez
    09 => casi y diez
    10 => y diez
    11 => y diez pasadas
    12 => y diez pasadas

    13 => casi y cuarto
    14 => casi y cuarto
    15 => y cuarto
    16 => y cuarto pasadas
    17 => y cuarto pasadas

    18 => casi y veinte
    19 => casi y veinte
    20 => y veinte
    21 => y veinte pasadas
    22 => y veinte pasadas

    23 => casi y veinticinco
    24 => casi y veinticinco
    25 => y veinticinco
    26 => y veinticinco pasadas
    27 => y veinticinco pasadas

    28 => casi y media
    29 => casi y media
    30 => y media
    31 => y media pasadas
    32 => y media pasadas

    33 => casi menos veinticinco
    34 => casi menos veinticinco
    35 => menos veinticinco
    36 => menos veinticinco pasadas
    37 => menos veinticinco pasadas

    38 => casi menos veinte
    39 => casi menos veinte
    40 => menos veinte
    41 => menos veinte pasadas
    42 => menos veinte pasadas

    43 => casi menos cuarto
    44 => casi menos cuarto
    45 => menos cuarto
    46 => menos cuarto pasadas
    47 => menos cuarto pasadas

    48 => casi menos diez
    49 => casi menos diez
    50 => menos diez
    51 => menos diez pasadas
    52 => menos diez pasadas

    53 => casi menos cinco
    54 => casi menos cinco
    55 => menos cinco
    56 => menos cinco pasadas
    57 => menos cinco pasadas

    58 => casi
    59 => casi

    */

    // indica si la hora se referencia a la actual o a la posterior
    bool hour_is_current = (minute < 33);

    // hora en formato 12 y referida
    byte hour_12 = (hour > 12) ? hour - 12 : hour;
    if (!hour_is_current) hour_12++;
    if (hour_12 == 13) hour_12 = 1;

    // indica si la hora es plural o singular
    bool hour_is_singular = (hour_12 == 1);

    // ARTICLE
    if (hour_is_singular) {
        _wordClockLoadCode((clockword) ESP_ES, pattern);
        _wordClockLoadCode((clockword) ESP_LA, pattern);
    } else {
        _wordClockLoadCode((clockword) ESP_SON, pattern);
        _wordClockLoadCode((clockword) ESP_LAS, pattern);
    }

    // BLOCKS
    byte reference = ((minute + 2) / 5) % 12;
    byte index = (minute + 2) % 5;
    if (reference == 0) {
        // NOP
    } else if (reference < 7) {
        _wordClockLoadCode((clockword) ESP_Y, pattern);
    } else {
        _wordClockLoadCode((clockword) ESP_MENOS, pattern);
    }
    if (reference ==  1) _wordClockLoadCode((clockword) ESP_CINCO_B, pattern);
    if (reference ==  2) _wordClockLoadCode((clockword) ESP_DIEZ_B, pattern);
    if (reference ==  3) _wordClockLoadCode((clockword) ESP_CUARTO, pattern);
    if (reference ==  4) _wordClockLoadCode((clockword) ESP_VEINTE, pattern);
    if (reference ==  5) _wordClockLoadCode((clockword) ESP_VEINTICINCO, pattern);
    if (reference ==  6) _wordClockLoadCode((clockword) ESP_MEDIA, pattern);
    if (reference ==  7) _wordClockLoadCode((clockword) ESP_VEINTICINCO, pattern);
    if (reference ==  8) _wordClockLoadCode((clockword) ESP_VEINTE, pattern);
    if (reference ==  9) _wordClockLoadCode((clockword) ESP_CUARTO, pattern);
    if (reference == 10) _wordClockLoadCode((clockword) ESP_DIEZ_B, pattern);
    if (reference == 11) _wordClockLoadCode((clockword) ESP_CINCO_B, pattern);

    // MODIFIERS
    if (index < 2) _wordClockLoadCode((clockword) ESP_CASI, pattern);
    if (index > 2) {
        if (hour_is_singular) {
            _wordClockLoadCode((clockword) ESP_PASADA, pattern);
        } else {
            _wordClockLoadCode((clockword) ESP_PASADAS, pattern);
        }
    }
    if (minute == 0) _wordClockLoadCode((clockword) ESP_EN_PUNTO, pattern);

    // HORAS
    switch (hour_12) {
        case  1: _wordClockLoadCode((clockword) ESP_UNA, pattern); break;
        case  2: _wordClockLoadCode((clockword) ESP_DOS, pattern); break;
        case  3: _wordClockLoadCode((clockword) ESP_TRES, pattern); break;
        case  4: _wordClockLoadCode((clockword) ESP_CUATRO, pattern); break;
        case  5: _wordClockLoadCode((clockword) ESP_CINCO, pattern); break;
        case  6: _wordClockLoadCode((clockword) ESP_SEIS, pattern); break;
        case  7: _wordClockLoadCode((clockword) ESP_SIETE, pattern); break;
        case  8: _wordClockLoadCode((clockword) ESP_OCHO, pattern); break;
        case  9: _wordClockLoadCode((clockword) ESP_NUEVE, pattern); break;
        case 10: _wordClockLoadCode((clockword) ESP_DIEZ, pattern); break;
        case 11: _wordClockLoadCode((clockword) ESP_ONCE, pattern); break;
        default: _wordClockLoadCode((clockword) ESP_DOCE, pattern); break;
    }

    // FRANJA HORARIA
    _wordClockLoadCode((clockword) ESP_DE_F, pattern);
    _wordClockLoadCode((clockword) ESP_LA_F, pattern);
    if (hour < 6) {
        _wordClockLoadCode((clockword) ESP_NOCHE, pattern);
    } else if (hour < 13) {
        _wordClockLoadCode((clockword) ESP_MANANA, pattern);
    } else if (hour < 21) {
        _wordClockLoadCode((clockword) ESP_TARDE, pattern);
    } else {
        _wordClockLoadCode((clockword) ESP_NOCHE, pattern);
    }

}
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

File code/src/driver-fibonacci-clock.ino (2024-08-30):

/*

FIBONACCI CLOCK DRIVER

Copyright (C) 2017-2024 by Xose Pérez <xose dot perez at gmail dot com>

*/

#if ENABLE_DRIVER_FIBONACCI

#include <FastLED_GFX.h>

// blocks are:
// number : 1, 2, 3, 4,  5
// binary : 1, 2, 4, 8, 16
// value  : 1, 1, 2, 3,  5
byte fibonacci_code_00[] = {0};
byte fibonacci_code_01[] = {1, 2};
byte fibonacci_code_02[] = {4, 3};
byte fibonacci_code_03[] = {8, 5, 6};
byte fibonacci_code_04[] = {7, 9, 10};
byte fibonacci_code_05[] = {16, 11, 12};
byte fibonacci_code_06[] = {18, 13, 14, 17};
byte fibonacci_code_07[] = {20, 15, 19};
byte fibonacci_code_08[] = {24, 21, 22};
byte fibonacci_code_09[] = {23, 25, 26};
byte fibonacci_code_10[] = {28, 27};
byte fibonacci_code_11[] = {30, 29};
byte fibonacci_code_12[] = {31};
byte* fibonacci_codes[13] = {
   fibonacci_code_00, fibonacci_code_01, fibonacci_code_02, fibonacci_code_03,
   fibonacci_code_04, fibonacci_code_05, fibonacci_code_06, fibonacci_code_07,
   fibonacci_code_08, fibonacci_code_09, fibonacci_code_10, fibonacci_code_11,
   fibonacci_code_12
};
byte fibonacci_options[13] = {1, 2, 2, 3, 3, 3, 4, 3, 3, 3, 2, 2, 1};

#if (MATRIX_SIZE == MATRIX_8x8 || MATRIX_SIZE == MATRIX_16x8)

// 00000000 0
// 55555333 1
// 55555333 2
// 55555333 3
// 55555122 4
// 55555122 5
// 00000000 6
// 00000000 7

unsigned int fibonacci_block_01a[] = {0x00, 0x00, 0x00, 0x00, 0x04, 0x00, 0x00, 0x00 };
unsigned int fibonacci_block_01b[] = {0x00, 0x00, 0x00, 0x00, 0x00, 0x04, 0x00, 0x00 };
unsigned int fibonacci_block_02[]  = {0x00, 0x00, 0x00, 0x00, 0x03, 0x03, 0x00, 0x00 };
unsigned int fibonacci_block_03[]  = {0x00, 0x07, 0x07, 0x07, 0x00, 0x00, 0x00, 0x00 };
unsigned int fibonacci_block_05[]  = {0x00, 0xF8, 0xF8, 0xF8, 0xF8, 0xF8, 0x00, 0x00 };

#else

// 0000000000000000 0
// 0000000000000000 1
// 5555555555333333 2
// 5555555555333333 3
// 5555555555333333 4
// 5555555555333333 5
// 5555555555333333 6
// 5555555555333333 7
// 5555555555112222 8
// 5555555555112222 9
// 5555555555112222 10
// 5555555555112222 11
// 0000000000000000 12
// 0000000000000000 13
// 0000000000000000 14
// 0000000000000000 15

unsigned int fibonacci_block_01a[] = {0x0000, 0x0000, 0x0000, 0x0000, 0x0000, 0x0000, 0x0000, 0x0000, 0x0030, 0x0030, 0x0000, 0x0000, 0x0000, 0x0000, 0x0000, 0x0000 };
unsigned int fibonacci_block_01b[] = {0x0000, 0x0000, 0x0000, 0x0000, 0x0000, 0x0000, 0x0000, 0x0000, 0x0000, 0x0000, 0x0030, 0x0030, 0x0000, 0x0000, 0x0000, 0x0000 };
unsigned int fibonacci_block_02[]  = {0x0000, 0x0000, 0x0000, 0x0000, 0x0000, 0x0000, 0x0000, 0x0000, 0x000F, 0x000F, 0x000F, 0x000F, 0x0000, 0x0000, 0x0000, 0x0000 };
unsigned int fibonacci_block_03[]  = {0x0000, 0x0000, 0x003F, 0x003F, 0x003F, 0x003F, 0x003F, 0x003F, 0x0000, 0x0000, 0x0000, 0x0000, 0x0000, 0x0000, 0x0000, 0x0000 };
unsigned int fibonacci_block_05[]  = {0x0000, 0x0000, 0xFFC0, 0xFFC0, 0xFFC0, 0xFFC0, 0xFFC0, 0xFFC0, 0xFFC0, 0xFFC0, 0xFFC0, 0xFFC0, 0x0000, 0x0000, 0x0000, 0x0000 };

#endif

unsigned int * fibonacci_blocks[5] = { fibonacci_block_01a, fibonacci_block_01b, fibonacci_block_02, fibonacci_block_03, fibonacci_block_05};

unsigned long fibonacci_colors[4];

unsigned char fibonacciPreviousMinute = 61;
unsigned char fibonacciPreviousHour = 25;

// -----------------------------------------------------------------------------
// DRIVER
// -----------------------------------------------------------------------------

unsigned char fibonacciClockRandomCode(unsigned int value) {
    byte * possible = fibonacci_codes[value];
    byte chosen = random(fibonacci_options[value]);
    return possible[chosen];
}

void fibonacciValueMatrix(unsigned int value, unsigned int * array) {

    unsigned char code = fibonacciClockRandomCode(value);

    unsigned block = 0;
    while (code > 0) {
        if ((code & 1) == 1) {
            for (unsigned char i=0; i<MATRIX_HEIGHT; i++) {
                array[i] = array[i] + fibonacci_blocks[block][i];
            }
        }
        ++block;
        code >>= 1;
    }


}

void fibonacciClockLoop() {

    RtcDateTime now = rtcGet();
    int currentMinute = now.Minute();
    int currentHour = now.Hour();
    if ((currentMinute == fibonacciPreviousMinute) && (currentHour == fibonacciPreviousHour)) return;
    fibonacciPreviousMinute = currentMinute;
    fibonacciPreviousHour = currentHour;

    // Load each value matrix separatelly
    unsigned int hours[MATRIX_HEIGHT] = {0};
    if (currentHour > 12) currentHour -= 12;
    fibonacciValueMatrix(currentHour, hours);
    unsigned int minutes[MATRIX_HEIGHT] = {0};
    fibonacciValueMatrix(currentMinute / 5, minutes);

    // Prepare the display
    matrixClear();

    // Walk the matrices choosing the colors
    #if (MATRIX_SIZE == MATRIX_8x8 || MATRIX_SIZE == MATRIX_16x8)
        int start = 1;
        int end = 6;
        int shift = (MATRIX_WIDTH / 2 - 4);
    #else
        int start = 2;
        int end = 12;
        int shift = 0;
    #endif

    for (unsigned char y = start; y < end; y++) {
        for (unsigned char x = 0; x < MATRIX_WIDTH; x++) {
            int value = ((hours[y] >> x) & 1) + 2 * ((minutes[y] >> x) & 1);
            matrixSetPixelColor(shift + MATRIX_WIDTH - x - 1, y, fibonacci_colors[value]);
        }
    }

    for (unsigned char n = 0; n < currentMinute % 5; n++) {
        #if (MATRIX_SIZE == MATRIX_8x8 || MATRIX_SIZE == MATRIX_16x8)
            matrixSetPixelColor(shift + MATRIX_WIDTH - n - 1, MATRIX_HEIGHT - 1, CRGB::Orange);
        #else
            matrixSetPixelColor(shift + MATRIX_WIDTH - n*3 - 1, MATRIX_HEIGHT - 1, CRGB::Orange);
            matrixSetPixelColor(shift + MATRIX_WIDTH - n*3 - 1, MATRIX_HEIGHT - 2, CRGB::Orange);
            matrixSetPixelColor(shift + MATRIX_WIDTH - n*3 - 2, MATRIX_HEIGHT - 1, CRGB::Orange);
            matrixSetPixelColor(shift + MATRIX_WIDTH - n*3 - 2, MATRIX_HEIGHT - 2, CRGB::Orange);
        #endif
    }

    matrixRefresh();

}

void fibonacciClockSetup() {

    fibonacci_colors[0] = 0x080808;
    fibonacci_colors[1] = CRGB::Red;
    fibonacci_colors[2] = CRGB::Green;
    fibonacci_colors[3] = CRGB::Blue;

    driverRegister(
        "Fibonacci clock",
        []{
            fibonacciPreviousMinute = 99;
            fibonacciClockLoop();
        },
        fibonacciClockLoop,
        NULL,
        driverCommonStatus, 
        driverCommonProgress
    );

}

#endif

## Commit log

2017-05-01 Initial version
    [slices.scad]
2019-12-29 Update case models
    [slices.scad, slices_v2.scad]
2019-12-29 Fix strings and OTA progress bar
    [general.h, matrix.ino, mdns.ino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]
2020-01-18 Fix button & WPS on boot
    [button.ino, general.h, wifi.ino]
2020-01-19 Change sync options order, make them work, small fixes
    [general.h, sound.ino, utils.ino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]
2020-01-19 Disable sound (too low)
    [slices.ino, sound.ino]
2020-01-21 Moved progress and status to drivers
2020-01-21 Option to set indication led to off after 5s when connected
2020-01-21 Further checking driver index
2020-01-21 Indication LED for wordclock
2020-01-21 Prevent auth connection when WPS
    [wifi.ino]
2020-01-21 Fix Basic clock driver
    [driver-basic-clock.ino]
2020-01-22 Gauge driver and small fixes
    [driver-circle-clock.ino, driver-gauge-clock.ino, driver-scroll-clock.ino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]
2020-01-22 Avoid plotting idle status on circle clocks
    [driver-circle-clock.ino, driver-gauge-clock.ino, driver-scroll-clock.ino]
2020-01-23 Added fibonacci mood driver

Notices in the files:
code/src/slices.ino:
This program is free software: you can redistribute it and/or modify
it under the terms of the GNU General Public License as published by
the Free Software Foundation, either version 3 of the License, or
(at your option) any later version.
